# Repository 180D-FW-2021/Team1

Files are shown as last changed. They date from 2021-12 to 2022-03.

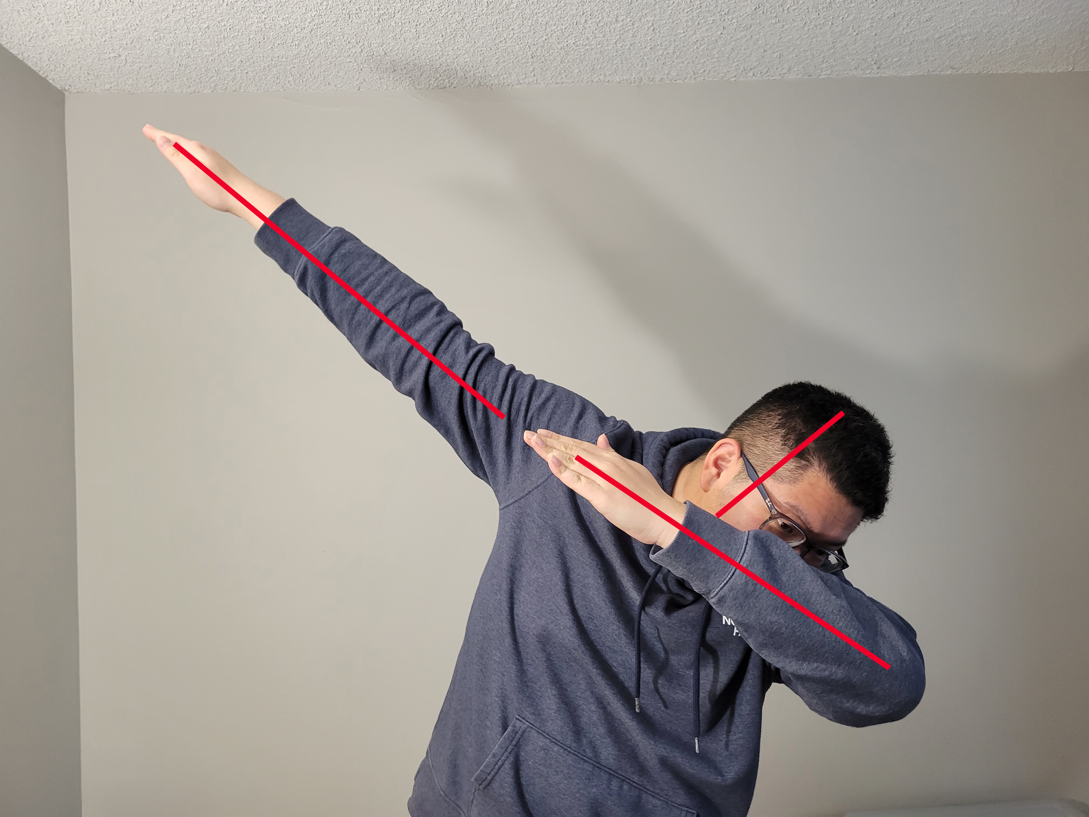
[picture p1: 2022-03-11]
gui/pose_images/Right-Dab.jpg

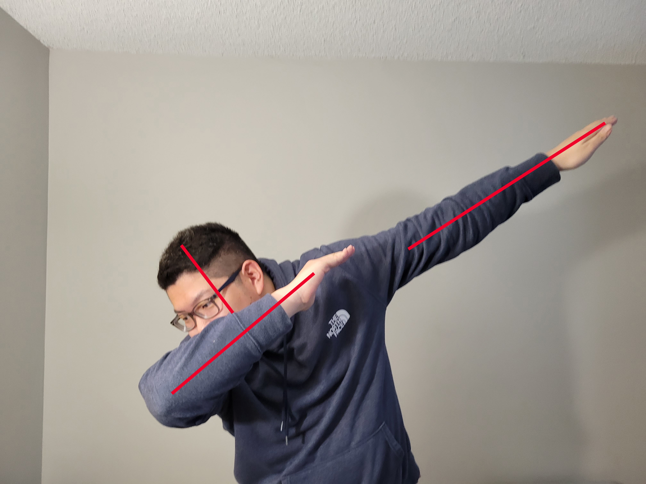
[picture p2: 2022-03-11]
gui/pose_images/Left-Dab.jpg

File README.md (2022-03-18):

# AirController

Being forced to get up and get the remote just to change the volume or channel is a hassle for households that use a TV. To fix this issue, we have decided to prototype AirController, a system that can take in gestures, poses, and speech as inputs and accordingly control a TV based on the user input. The user can make a specific gesture using their hands or body in order to control the TV, or otherwise issue speech commands to control it that way. These alternate control methods aid those who are disabled and unable to use a normal TV remote, as well as those who are not currently within reach of a remote and do not want to go searching for it.

Currently, the AirController can support 5 commands: Power, Channel Up/Down, and Volume Up/Down. These 5 commands are activated in one of three ways: striking a pose in front of the webcam, moving the hand holding a BerryIMU, or speaking a command. 

## Pose Recognition (OpenCV and MediaPipe)
Uses computer vision and image processing to detect specific body positions and poses. Uses MQTT to communicate detected poses to the subscriber Raspberry Pi.

Folder: sample_poses show images of sample poses that are to be detected from the AirController.

Directory: `pose_detection_code`

## Speech Recognition
Uses Google Cloud Speech-to-Text to detect keywords for specific voice commands.  Uses MQTT to communicate detected commands to the subscriber Raspberry Pi.

Directory: `speech`

## Gesture Recognition
Uses a programmed BerryIMU to detect specific hand motions. Uses MQTT to communicate detected gestures to the subscriber Raspberry Pi.

Directory: `gesture`

## GUI
Graphical user interface created with TKinter to help the user orient themselves with the product. Includes video tutorials of how to use the product. Launches the speech recognition and pose recognition modules on the user's computer.

Directory: `gui`

## Communications
Communication interface for the two Raspberry Pis and laptop to talk to one another and the TV. Uses MQTT publisher/subscriber model. Requires paho-mqtt Python library.

Directory: `comms`

## Demonstration
Demonstrations of our individual subcomponents of our projects working.

Directory: `demonstration_videos`

## Download & Set-Up
Please follow the user manual for detailed instructions on how to set up the AirController.

## Controls

Pose (Webcam) - current poses include a right dab (volume up), left dab (volume down), both arms at a 90 degree angle (channel up), both hands together (power), both arms straight and body straight (power), and both arms straight and both legs at a 90 degree angle (channel down). The webcam must properly recognize the user first for it to start working. 

Speech - currently supports keyword detection for "volume", "channel", and "power". To adjust volume, say any combination of "volume" and "up/down". To adjust channel, say any combination of "channel" and "up/down". To turn the TV on or off, say any combination of "power" and "on/off".

Gesture (BerryIMU) - possible gestures include tilt right (volume up), tilt left (volume down), flick right (channel up), flick left (channel down), flick up (power on), and flick down (power off). The BerryIMU should be facing forward and parallel to the ground as its neutral position. For a visual explanation, launch gui.py and view the tutorial videos.

## Credits

Developed by Steven Chu, Maksym Prokopovych, Sierra Rose, and Isaac Xu.

IMUpi.py: this file, and others in the `gesture` directory, are adapted from http://github.com/ozzmaker/BerryIMU.git. 

mainPi.py: this file, and others in the `comms` directory, are adapted from lab 3. Configuring LIRC adapted from https://www.hackster.io/austin-stanton/creating-a-raspberry-pi-universal-remote-with-lirc-2fd581

pose.py: this file, and others in the `pose_detection_code` directory, are adapted from lab 1 as well as various online sources, which are further referenced in the README of the `pose_detection_code` directory. Also adapted from https://bleedai.com/, specifically https://bleedai.com/introduction-to-pose-detection-2/ and https://bleedai.com/introduction-to-pose-detection-and-basic-pose-classification/

speech_processing.py: this file, and others in the `speech` directory, are adapted from example code provided by Google Cloud documentation.
https://cloud.google.com/speech-to-text/docs/samples?hl=en_US

Further credits can be found in the READMEs of each directory.

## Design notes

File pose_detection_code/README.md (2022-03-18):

## Credits

Isaac Xu's responsibility

## Contents

check_dab.py
  - demo code for detecting if a person is in a dab position

check_psy.py
  - demo code for detecting if both arms are at a 90 degree angle
 
check_three_pose.py
  - demo code for detecting three poses: T-pose, tree pose, and Warrior II pose
  
gui_pose_test.py
  - demo code for combining gui and posture detection code
  
hands_together.py
  - demo code for detecting if a person has their hands in close contact
  
jump_stand.py
  - demo code for detecting if a person is either jumping, crouching, or standing
  
left_right.py
  - demo code for detecting if a person is on the right side, left side, or center of the webcam
  
poses.txt
  - current list of poses and how to achieve them
  
together.py
  - posture detection code that detects a right or left dab, arms at 90 degrees, hands placed together, a T-pose, and both arms straight and legs at 90 degrees
  - sends it to poses.py in the main folder so that the command corresponding to the pose is executed
  - requires one available webcam on the computer

Pose Detect.mp4
  - posture detection code in action, showing that dabs change the volume, and a hands-together and T-pose "presses" the power button
  - having both arms at 90 degree angle, or having both arms straight while legs are at a 90 degree angle would change the channel up and down, but that T.V didn't have any channels to change. The signal was still sent to the mqtt.

Pose Detection Trials.mp4
  - all the trials done to detect if there was any errors when detecting poses 

Pose_Demonstration.mp4
  - a demonstration of how to properly use the pose detection to control the AirController

dependencies.txt
  - a list of all the dependencies Isaac's virtual environment uses to run pose detection code

pose_install_script.sh
  - make sure to run this, since it contains the modules that are required to run both pose detection and speech detection code

testing.py
  - testing code that won't interfere with the main approved detection

required installs.txt
  - a list of the required installs (besides those already in Anaconda) needed to run only pose detection code

## Code tags
  Where Isaac got help for the code from
  - https://bleedai.com/introduction-to-pose-detection-2/
  - https://bleedai.com/introduction-to-pose-detection-and-basic-pose-classification/

## Known Bugs

## Improvements
- organize list of dependencies (current list is 300 above dependencies)

## Decisions Made
- this was the default
- current list of poses used because they are easily identifiable and easily done by majority of people, but might have to change in the future
- 6 poses used: two for power, two for channel, two for volume

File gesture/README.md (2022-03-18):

## Credits

All of the code in this directory which gathers sensor information from the BerryIMU is adapted from http://github.com/ozzmaker/BerryIMU.git.

This portion of the project was Sierra's responsibility.

## Information and Statistics

This code gathers a bunch of data from the BerryIMU sensors, sets arbitrary thresholds to detect when certain gestures are executed, and sends MQTT messages to our server with which gesture was detected. There are various flags to detect when a gesture was just made so as to prevent the detection of its opposite gesture within a certain time frame, as many gestures require the Pi to be put back in its original position after. 

Currently, the gesture accuracy is as follows:

Power off: 93%

Power on: 100%

Volume down: 100%

Volume up: 100%

Channel down: 100%

Channel up: 100%

Fall detection: 81%

More statistics can be found in the `gesture_data` directory. The latest data is within `winter_data_final`.

I first made the decision to use the accXangle when detecting volume up/down because it was the value that changed the most while making the gesture and just reading the raw data of the BerryIMU. However, it is somewhat unreliable due in part to its noisiness, and so I will be reviewing my choice of variable next quarter.

I also then made the choice to use faux derivatives in creating difference_gyro_X/difference_gyro_Z to use for detecting "flicking" motions (channel up/down, power on/off). This is because they are much easier than actually deriving anything in Python, and because they serve the same purpose: to see the change over time within a certain reading. By making these faux derivatives of the gyro_X and gyro_Z readings of the BerryIMU, I was able to detect when the user rapidly flicked their IMU in a given direction to be able to detect these gestures.

Similarly, I also created difference_gyro_Y, which is solely used to detect when the Pi is falling. Fall detection has about 81% accuracy in detecting a fall (only tested without the case due to movement constraints with the shorter wire). While detecting falls is important, perhaps more important is not ignoring a user's input, thus causing the fall detection to not be perhaps as sensitive as it could be to get 95%+ accuracy. However, this enables the user to not have their inputs ignored, which is definitively more important than successfully detecting a fall to block excess inputs. Thus, while improvements may be possible, we are satisfied with where the fall detection currently is.

## In the main directory, IMUpi.py is the actual file to run in order to use the files within this directory. None of these files should be executed directly.

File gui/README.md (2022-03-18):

## Credits

This part of the project was everyone's responsibility.

Sierra began the GUI by creating some skeleton code for it, which included the general aesthetic, buttons, and ideas of what to include (such as tutorial videos). 
Steven implemented the tutorial play video buttons, and the controller launch/stop buttons. Isaac implemented more buttons, some layout changes, and the tutorial pictures for his section.

To play a tutorial video, click a button under the "Tutorial Videos" tab. To open a tutorial picture, simply click on the button corresponding to the command you wish to enact. 

To start the controller, press "Start Controller". To stop, press "Stop Controller". There are also options to start only a section of the controller in case that is your preference.

Before running the code, please execute the following commands:
```
pip install python-tk
pip install imageio
pip install playsound
brew install portaudio
```

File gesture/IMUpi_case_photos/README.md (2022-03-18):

This is both the CAD files and a collection of photos showing what the IMU case looks like once printed. There is a hole present for any wires to run through (primarily to recharge the battery onboard). The wire in the photos has been moved out of the way so that you can see the internals. The case was designed and printed by Maksym.

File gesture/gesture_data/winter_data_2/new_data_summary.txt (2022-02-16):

Turn left (volume down):
34/34

Turn right (volume right):
30/31

Flick left (channel down):
31/31

Flick right (channel up):
22/26

Flick up (power on):
25/25

Flick down (power off):
26/27

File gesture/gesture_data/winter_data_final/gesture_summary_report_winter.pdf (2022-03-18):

BerryIMU Gesture Data Breakdown

Filename | Command | Gesture | Variable | Threshold | Accuracy
Turn_right_final_data | Volume up | Tilt right | accYangle | -180 < aYa < -70 | 100%
Turn_left_final_data | Volume down | Tilt left | accYangle | 180 > aYa > 70 | 100%
Flick_right_final_data | Channel up | Flick left | difference_gyro_Z | d_g_Z < -20 | 100%
Flick_left_final_data | Channel down | Flick right | difference_gyro_Z | d_g_Z > 20 | 100%
Flick_up_final_data | Power on | Flick up | difference_gyro_X | d_g_X < -25 | 100%
Flick_down_final_data | Power off | Flick down | difference_gyro_X | d_g_X > 40 | 93%
Fall_detection_data (found within gesture/gesture_data /winter_data_3/ ) | Fall detection | Falling (drop-ping the IMU) | difference_gyro_X, difference_gyro_Y, difference_gyro_Z | (d_g_X > 40 or d_g_X < -40) AND ((d_g_Y < -20 or d_g_Y > 20) OR (d_g_Z < -20 or d_g_Z > 20)) | 81%

BerryIMU gestures with their corresponding commands, as well as the accuracy percentages of each gesture being successfully recognized as its corresponding command, in addition to the variable measured alongside its threshold. Each gesture/command combo underwent 27-38 trials, wherein no output was observed by Sierra such that whether or not a gesture worked correctly was unknown until after the trial ended. AccYangle is a reading taken from the original BerryIMU code Sierra modified from lab 4. Difference_gyro_X, difference_gyro_Y, and difference_gyro_Z are faux derivatives that Sierra created in order to detect change over time between readings of the gyroscope’s sensors, allowing her to detect large changes in its readings in order to accurately recognize a gesture. These readings were all done with the case on the BerryIMU/Raspberry Pi/battery pack, with the exception of the fall_detection_data, where the wire to be used with the case was not long enough to test dropping the BerryIMU.

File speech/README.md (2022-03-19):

## Credits

This part of the project was Steven's responsibility.

Contains `speech_processing.py`, which implements the speech processing module of this project. Transcribes all audio to text, and detects keywords "power", "channel", and "volume".

Code adapted from Google Cloud Speech-to-Text API example code:
https://cloud.google.com/speech-to-text/docs/samples?hl=en_US

In order to run this code, please run the following commands:
```
pip install --upgrade google-cloud-speech
brew install portaudio
pip install pyaudio
```

Also required to run this code is a Google Cloud private key. It has been removed from this public repository, but is available upon request.
After obtaining the key, append `export GOOGLE_APPLICATION_CREDENTIALS="KEY_PATH"` to your ~/.bash_profile file, replacing "KEY_PATH" with the path to the private key on your local machine, and restart your shell.

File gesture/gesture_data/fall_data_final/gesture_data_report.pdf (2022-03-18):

BerryIMU Gesture Data Breakdown

File Directory | Command | Gesture | Variable | Threshold | Accuracy (20 trials)
Right_data | Volume up | Tilt right | accYangle | -180 < aYa < -70 | 60%
Left_data | Volume down | Tilt left | accYangle | 180 > aYa > 70 | 60%
Flick_right_data | Channel up | Flick left | difference_gyro_Z | d_g_Z < -20 | 90%
Flick_left_data | Channel down | Flick right | difference_gyro_Z | d_g_Z > 20 | 85%
Flick_up_data | Power on | Flick up | difference_gyro_X | d_g_X < -40 | 95%
Flick_down_data | Power off | Flick down | difference_gyro_X | d_g_X > 40 | 35%

BerryIMU gestures with their corresponding commands, as well as the accuracy percentages of each gesture being successfully recognized as its corresponding command, in addition to the variable measured alongside its threshold. Each gesture/command combo underwent 20 trials, wherein no output was observed by Sierra such that whether or not a gesture worked correctly was unknown until after the trial ended. AccYangle is a reading taken from the original BerryIMU code Sierra modified from lab 4. Difference_gyro_X and difference_gyro_Z are faux derivatives that Sierra created in order to detect change over time between readings of the gyroscope’s sensors, allowing her to detect large changes in its readings in order to accurately recognize a gesture.

Each directory contains an excel spreadsheet that graphs out each trial of each gesture. Not every graph is correctly labeled, as Sierra only took graphs of interest for such things as the final project report. From there, she put the number of correctly detected gestures somewhere beneath the graphs. All the other files in these directories just contain raw data. The excel spreadsheet compiles them together in a more compact format, but still without labels. For what exactly is being measured, please refer to the above table.

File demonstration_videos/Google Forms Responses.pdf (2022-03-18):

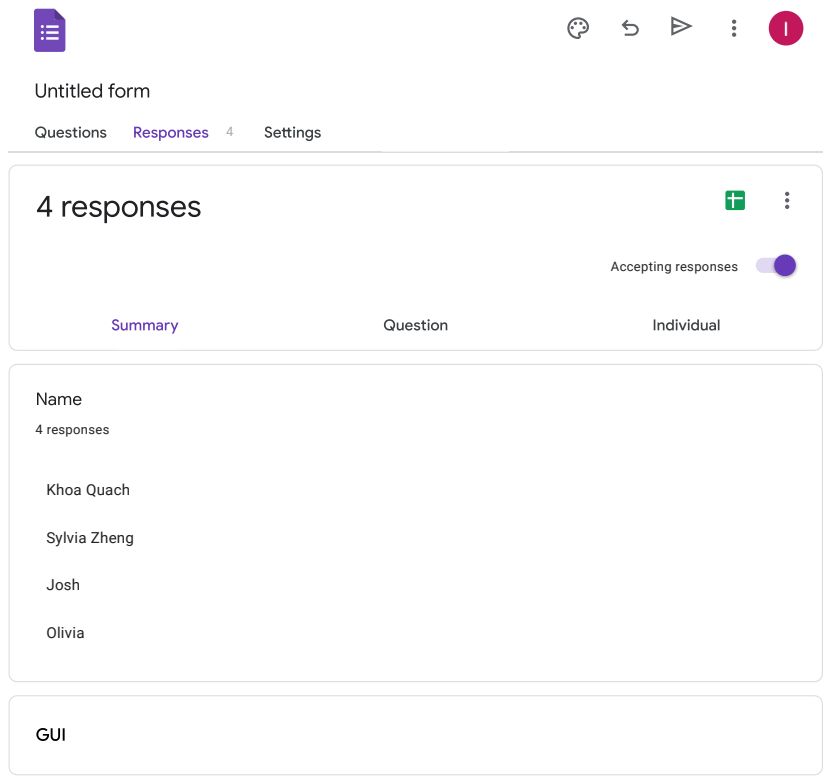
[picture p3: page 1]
4 responses; Accepting responses; Name; Khoa Quach; Sylvia Zheng; Josh; Olivia; GUI; Summary; Question; Individual; Untitled form; Questions; Responses; Settings

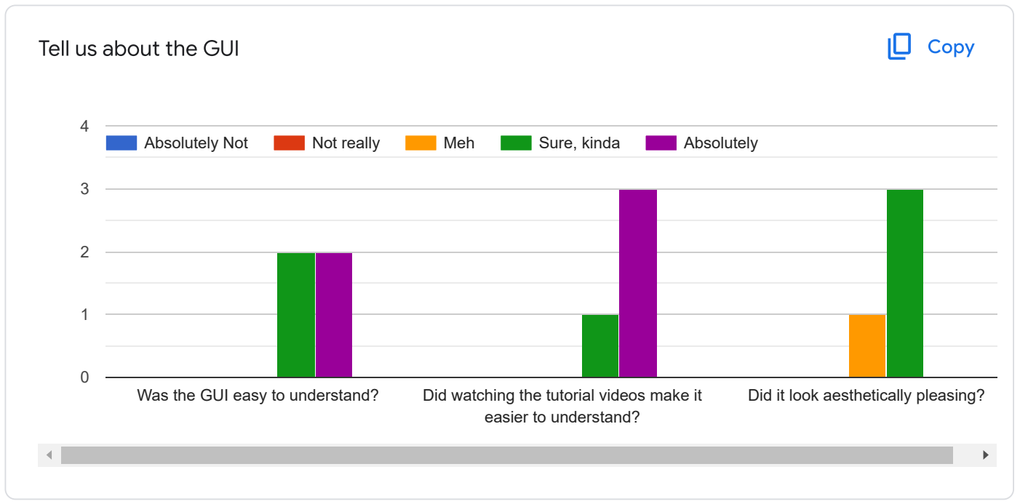
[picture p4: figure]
Tell us about the GUI; Copy; easier to understand?; Did it look aesthetically pleasing?; Absolutely Not; Not really; Meh; Sure, kinda; Absolutely

Are there any improvements/suggestions you have for the GUI?

3 responses

UI is pretty clean and buttons are self-explanatory. I think it might be more user-friendly if you could open the pose videos from the pose recognition page

Nothing really, it does its job

The GUI is great functionally, and I really appreciated all the tutorial videos. I'm not sure if you guys had this, but maybe showing a window of the pose webcam feed within the GUI would make it look more cohesive? Also, if you guys have the time, just minor improvmenets to make the GUI aesthethic :)

Was the GUI easy to understand? Did watching the tutorial videos make it

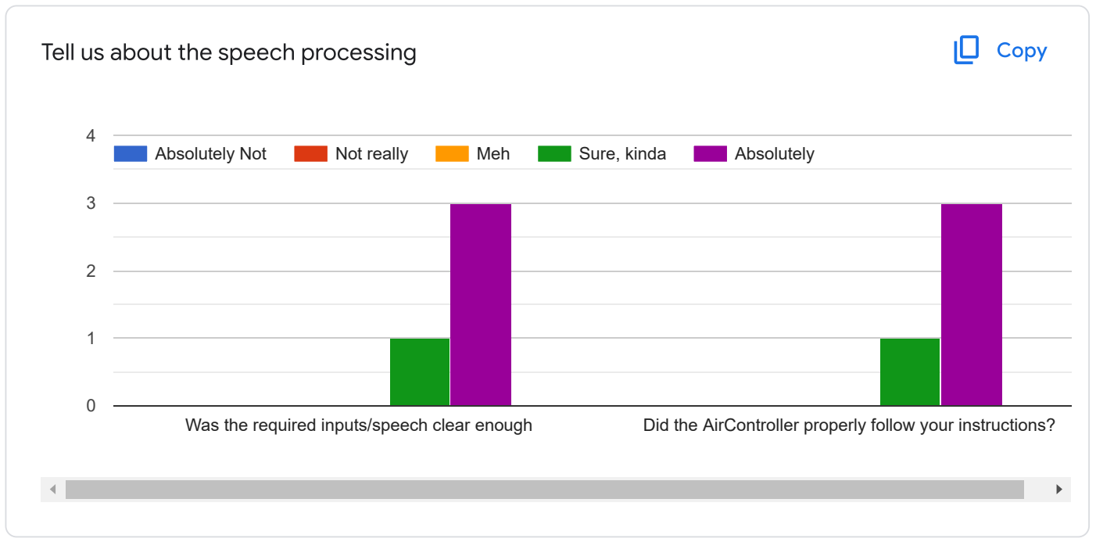
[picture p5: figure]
Tell us about the speech processing; Absolutely Not; Not really; Meh; Sure, kinda; Absolutely
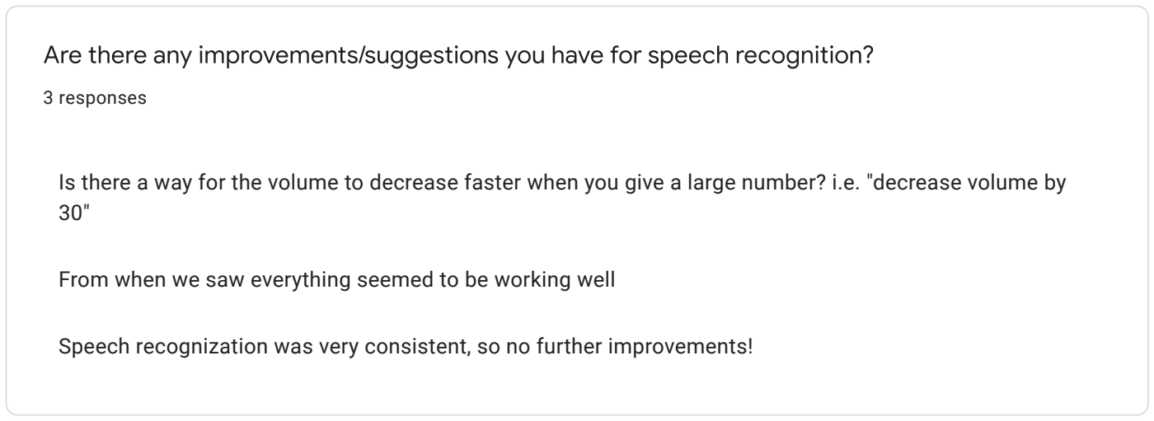
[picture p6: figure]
3 responses

Are there any improvements/suggestions you have for speech recognition?

Is there a way for the volume to decrease faster when you give a large number? i.e. "decrease volume by

From when we saw everything seemed to be working well

Speech recognization was very consistent, so no further improvements!

Was the required inputs/speech clear enough | Did the AirController properly follow your instructions?

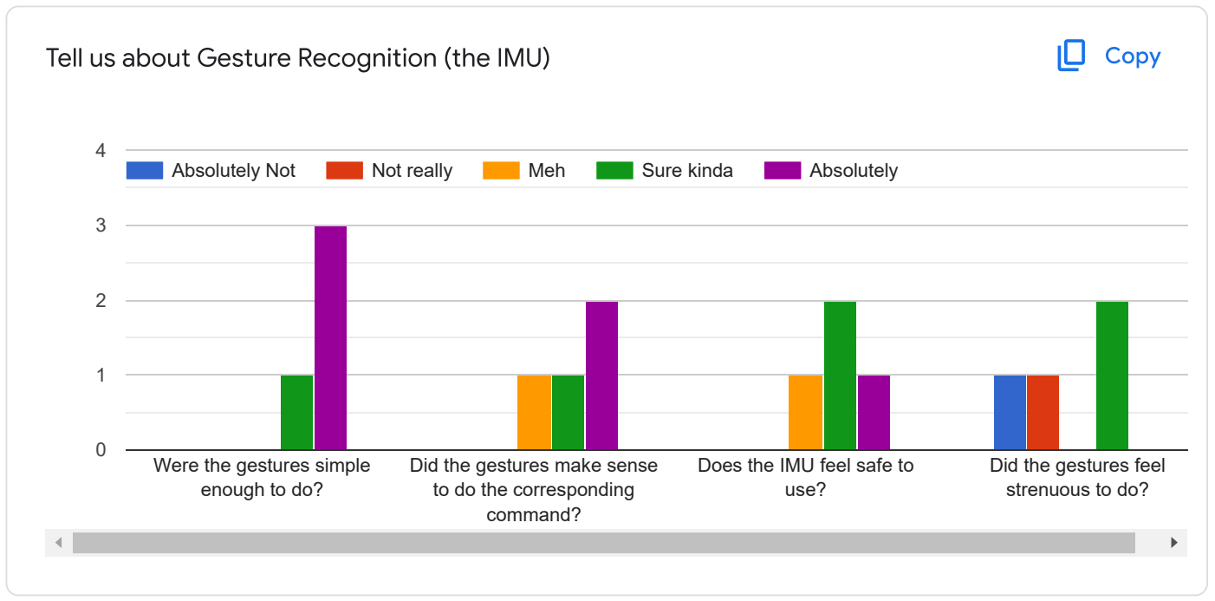
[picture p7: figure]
Were the gestures simple enough to do?; Did the gestures make sense to do the corresponding command?; Does the IMU feel safe to use?; Did the gestures feel strenuous to do?; Absolutely Not; Not really; Meh; Sure kinda; Absolutely

Tell us about Gesture Recognition (the IMU)

Are there any improvements/suggestions you have for gesture recognition?

4 responses

disconnecting issues, but works fine when connected

put the IMU in a box or find some way to keep it together with the Pi. Add some exception handling for if the IMU disconnects

I think just the connection problems were the only issue here

The IMU seemed to disconnect a lot while use, so maybe if soldering it or some other way to keep the wires from detaching can be helpful in making the gesture recognition system more consistent.

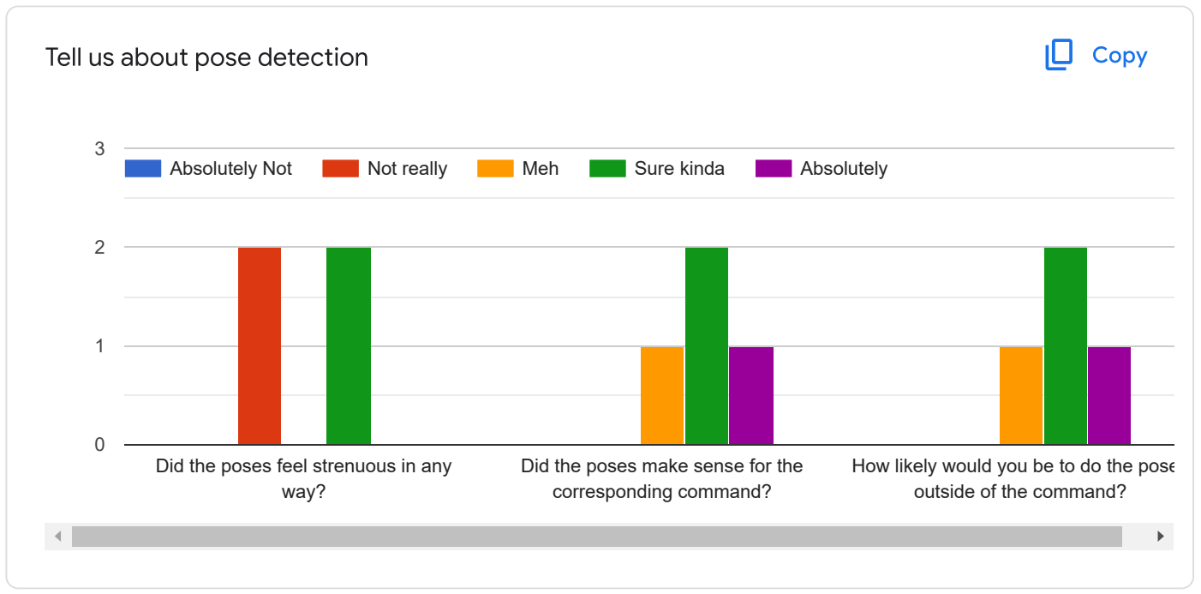
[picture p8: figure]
Tell us about pose detection; Did the poses feel strenuous in any way?; Did the poses make sense for the corresponding command?; How likely would you be to do the pose outside of the command?; Absolutely Not; Not really; Meh; Sure kinda; Absolutely
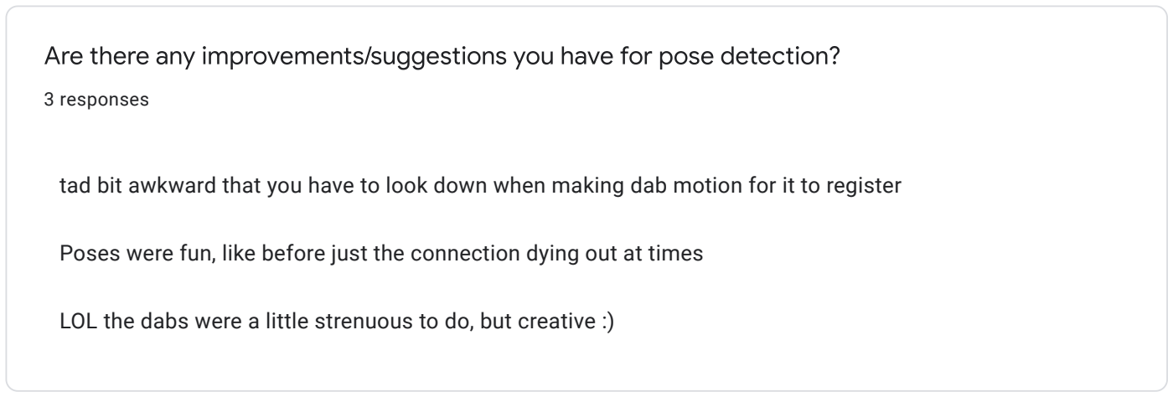
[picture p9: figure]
3 responses

Are there any improvements/suggestions you have for pose detection?

tad bit awkward that you have to look down when making dab motion for it to register

Poses were fun, like before just the connection dying out at times

LOL the dabs were a little strenuous to do, but creative :)

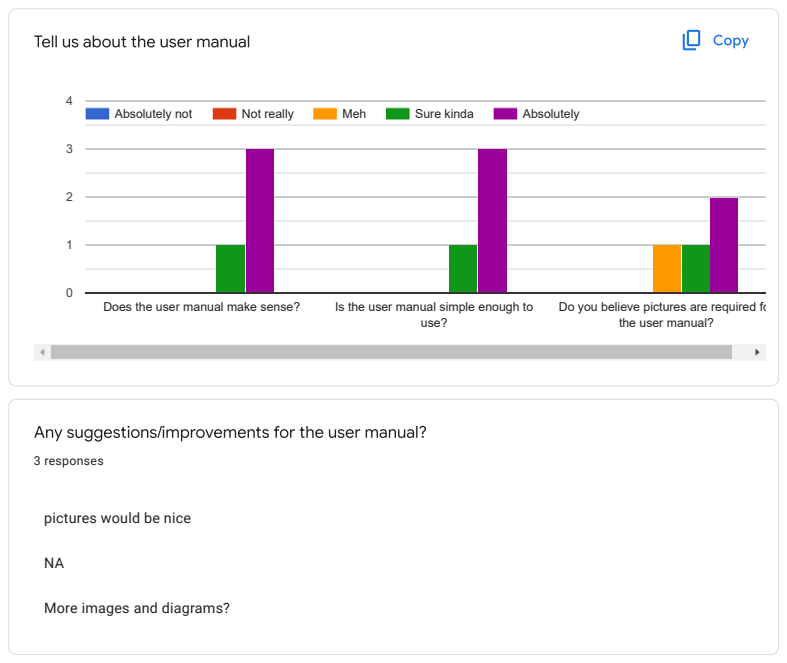
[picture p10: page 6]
3 responses; Does the user manual make sense?; Is the user manual simple enough to; use?; Absolutely not; Not really; Meh; Sure kinda; Absolutely

Tell us about the user manual

Do you believe pictures are required fo

the user manual?

Any suggestions/improvements for the user manual?

pictures would be nice

More images and diagrams?

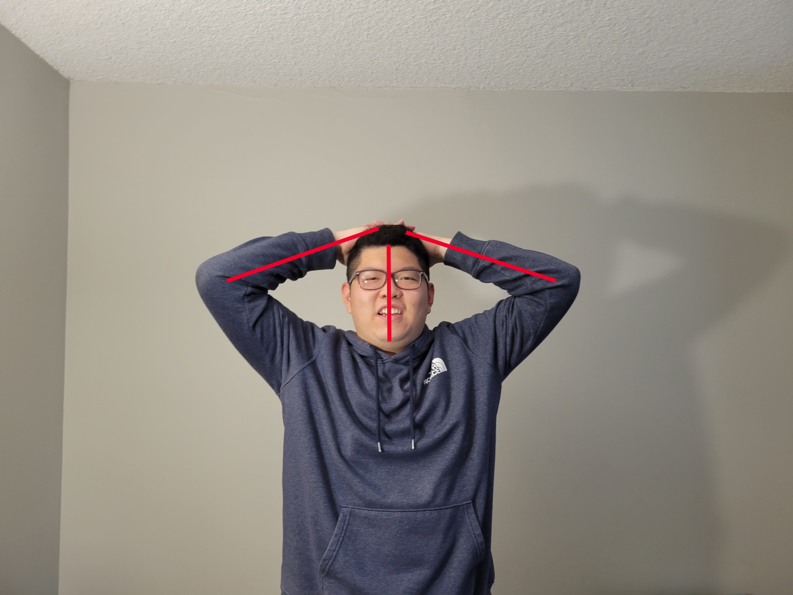
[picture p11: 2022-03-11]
gui/pose_images/Relaxing.jpg

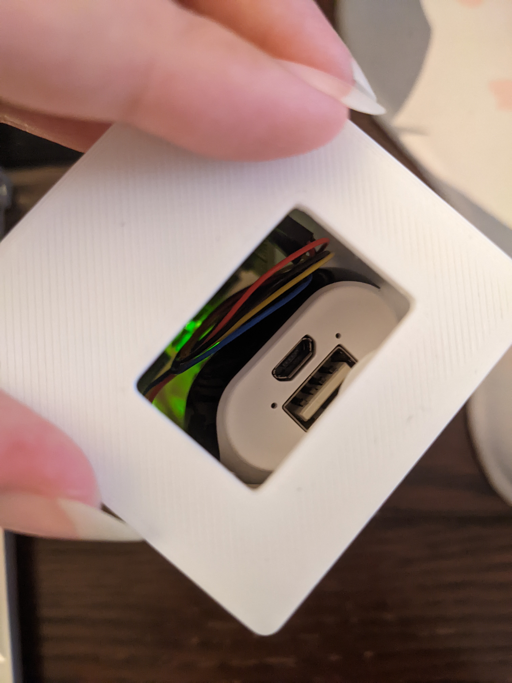
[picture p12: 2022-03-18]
gesture/IMUpi_case_photos/IMUpi_case4.jpg

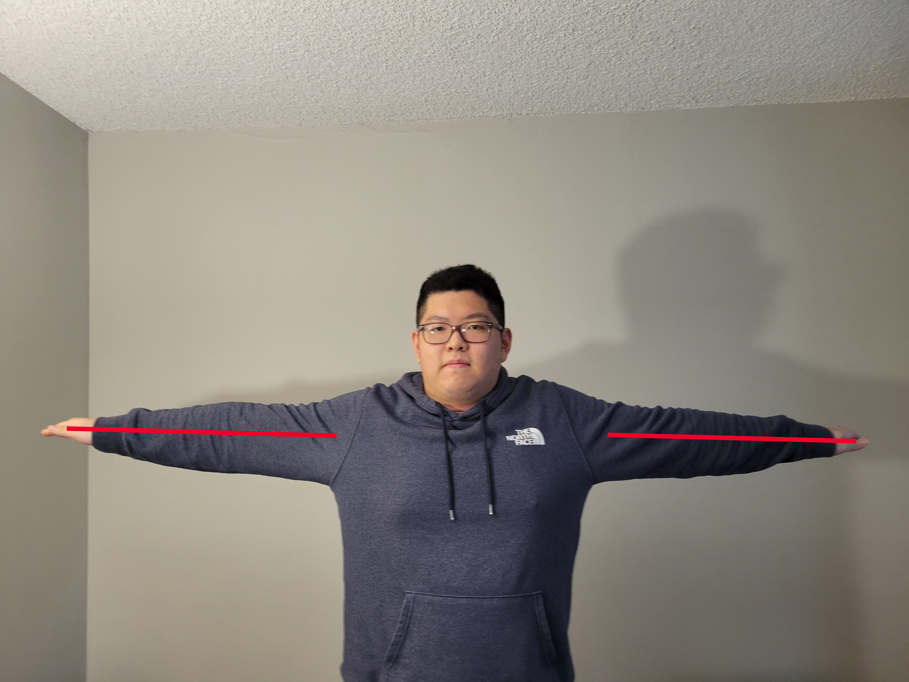
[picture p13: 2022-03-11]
gui/pose_images/T-pose.jpg

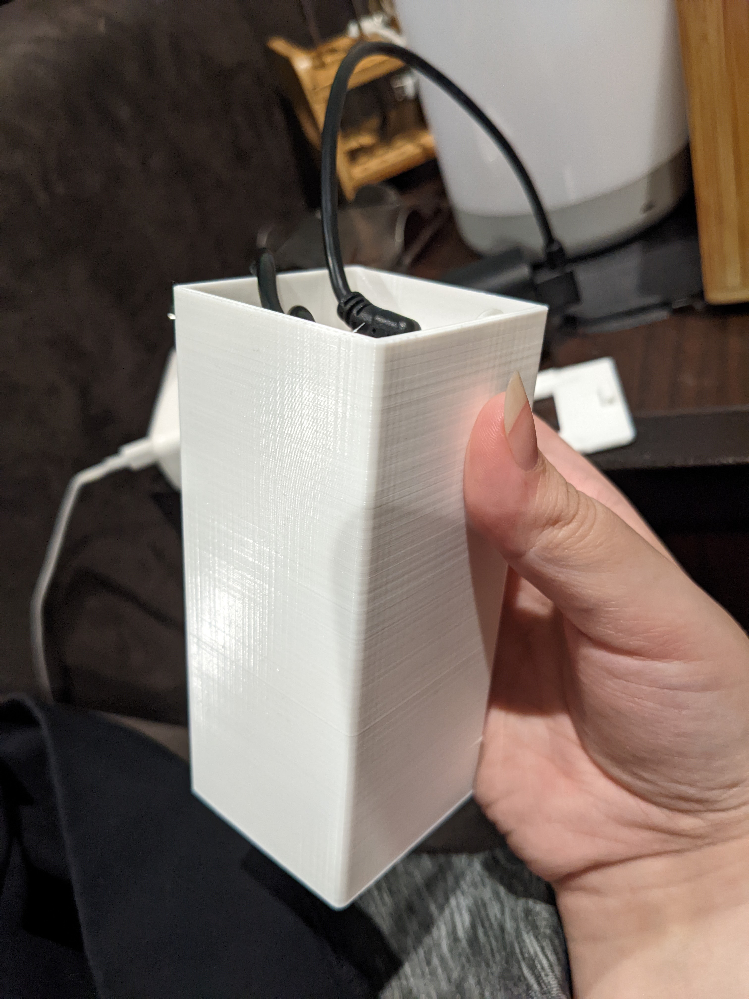
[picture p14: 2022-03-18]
gesture/IMUpi_case_photos/IMUpi_case1.jpg

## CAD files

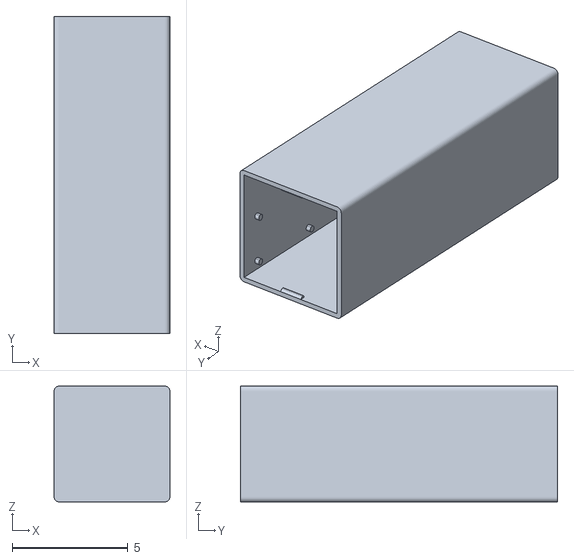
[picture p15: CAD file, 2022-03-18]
gesture/IMUpi_case_photos/180caseMain.stl
5.00 x 13.7 x 5.00

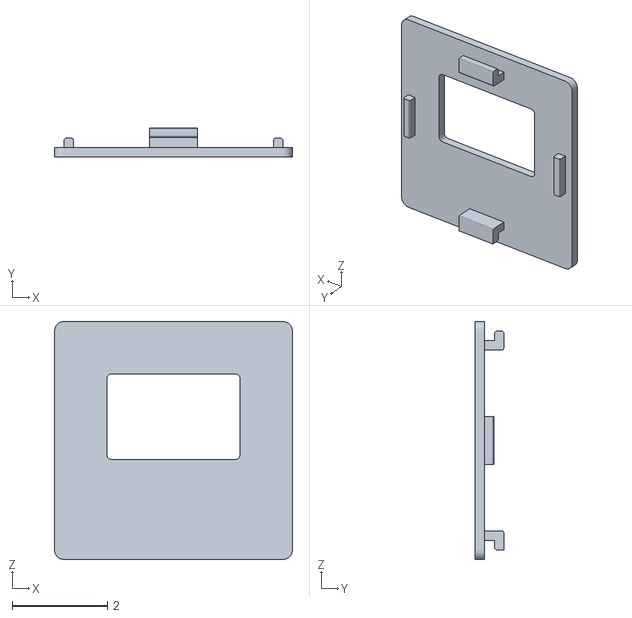
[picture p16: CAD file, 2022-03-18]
gesture/IMUpi_case_photos/180caseTop.stl
5.00 x 0.61 x 5.00

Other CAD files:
gesture/IMUpi_case_photos/180caseMain.ipt
gesture/IMUpi_case_photos/180caseTop.ipt

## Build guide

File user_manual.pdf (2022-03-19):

# AirController User Manual

Steven Chu, Maksym Prokopovych, Sierra Rose, Isaac Xu ECE 180DB, Winter 2022

### Getting Started

Hardware Requirements

The AirController has the following hardware requirements:

1. Two Raspberry Pi Zeros
2. BerryIMU
a. Jumper cables
3. IR emitter and receiver
a. Wires and breadboard to connect these together with one of the Raspberry Pis
4. A computer with a webcam and microphone
5. Wifi signal

Hardware Set-Up

While in an ideal scenario, the user would not be doing any of this set-up as the entire product would come preconfigured, in order to install the AirController onto pre-existing devices, the following set-up must be carried out.

For the first Raspberry Pi, we must set up the BerryIMU with 4 jumper cables, as well as enable I2C communication. For detailed instructions on how to do this, please refer to Lab 4 from fall quarter.

For the second Raspberry Pi, we must set up the IR emitter. The emitter is a standalone 3 pin device, it requires 3 pins, 3.3 V power, ground, and signal pins. The default signal pin is GPIO22, the 8th pin down on the left row of the header, with the “top” being the SD card slot.

If the user so desires, we have also provided CAD files to 3D print a case for the BerryIMU + Raspberry Pi + a suitable battery. While not necessary, the case helps to make the BerryIMU Raspberry Pi more robust, and contributes to a wireless solution for it.

Downloading and Installation

Connect to wifi on both of the Raspberry Pis, as well as the webcam and microphone-enabled computer. From there, download the Team 1 Github repo onto all of the devices. If trouble is experienced with this step, please skip to the disk imaging section below for further instructions on how to connect to wifi.

Computer Set-up

On the webcam and microphone-enabled computer, you must install the necessary software using the installation scripts. If you do not already have Python and pip installed, then please follow these steps:

Download an Anaconda environment (Python)
First run conda install pip -> this will install the pip directory
If it’s already installed, update pip, or skip this step entirely

If the user is struggling to run the given scripts (such as in the case of having a Windows computer), please run each given command in the scripts individually by first installing the necessary software, including Python and pip. This will enable the user to run most commands in the script. The user can skip any commands which do not run aside from these necessary ones using pip, such as apt-get. Please follow the commands listed within total_install_script.sh.

If the user already has Python and pip installed, then please run the total_install_script.sh file to install the AirController.

Raspberry Pi Set-up

On the first Raspberry Pi which is connected to the BerryIMU, run the IMUpi_install_script.sh present within the gesture folder. This will install the necessary dependencies. If desired, follow the instructions within system_config_information.txt in the gesture folder for how to make the program run on boot. Alternatively, you may flash the disk image provided. Further instructions on how to do that can be found below.

On the second Raspberry Pi which is connected to the IR emitter, you can either follow the detailed instructions within the lirc_configs folder’s README, or you can install the disk image provided (preferable). This is because the disk image has everything configured already for IR emission on pin 22 and automatic startup on boot.

Disk Imaging (optional)

Disk imaging can be accomplished with the .iso file by taking your favorite disk image utility (Rufus, dd, etc) and inputting the .iso file, and flashing an SD card with it.

Disk images for the IMU Pi & IR Pi can both be found at: https://drive.google.com/drive/folders/1LgcZ9hz0c_c1fFU0opW7Ngrds5oL3GBd?usp=sharing .

The only change required once imaging on each Pi is changing the wpa_supplicant.conf file (in /etc/wpa_supplicant/wpa_supplicant.conf) to support your local wifi network. Additionally, on the IR Pi, you must select the type of TV used in /home/pi/AirController/config.py. These can be edited either on the SD card itself or by sshing into the Pi (uses the default pi username and password).

### How to Use

The AirController has 3 ways to control a TV. The first is via whole-body poses recognized by the webcam. The second is through gestures using the BerryIMU-enabled Raspberry Pi. The third is via voice commands as heard by the computer. In order to best use each of these components, please continue reading to determine how to control each section.

Webcam-Detected Poses

These are the current postures that would trigger a command. To use, the person must be in camera view such that the upper body is within view, and the person must properly be detected. There must be sufficient lighting so that the camera can see one, and darker color clothing may need to be removed.

Command | Gesture(s) | Requirements
Volume Up | Right Dab | - Head into the right elbow - Distance between head and elbow doesn’t have to be too extreme - Left arm straight and some distance from the right arm
Volume Down | Left Dab | - Head into the left elbow - Distance between head and elbow doesn’t have to be too extreme - Right arm straight and some distance from the left arm
Channel Up | Arms Straight | - Arms make a 180 degree, from left to right - Arms are parallel to the ground - Arms must be in full view
Channel Down | Muscle Man | - Arms are at 90 degree, hands facing upward - Arms must be in full view
Power On/Off | Hands Together Relaxing | Hands Together - Have both hands be touching each other - Wrists must be in full view Relaxing - Have both hands be on top of the head; order doesn’t matter - Wrists must be in full view

BerryIMU Gestures

There are currently 6 possible gestures which you can use to control your TV. Each gesture corresponds to a different command, with detailed tutorial videos being accessible through the GUI for extra assistance. The commands are as follows:

Command | Gesture | Detailed Explanation
Volume up | Tilt right | The BerryIMU should be parallel to the floor while you attempt this gesture. With the BerryIMU and Raspberry Pi combo facing forwards, tilt the entire device to the right.
Volume down | Tilt left | The BerryIMU should be parallel to the floor while you attempt this gesture. With the BerryIMU and Raspberry Pi combo facing forwards, tilt the entire device to the left.
Channel up | Flick right | With the BerryIMU and Raspberry Pi combo facing forwards, quickly flick the device to the right by flicking your wrist outwards.
Channel down | Flick left | With the BerryIMU and Raspberry Pi combo facing forwards, quickly flick the device to the left by flicking your wrist inwards.
Power on | Flick up | With the BerryIMU and Raspberry Pi combo facing forwards, quickly flick the device up.
Power off | Flick down | With the BerryIMU and Raspberry Pi combo facing forwards, quickly flick the device down. It is okay to lift the device first when attempting to flick down.

It is helpful to always have the BerryIMU and Raspberry Pi facing forwards towards the TV, as well as parallel to the floor. When setting down the device, do so without tilting the Pi such that it does not think you are attempting to turn off the TV. The BerryIMU also supports fall detection, so dropping the device (in most cases) will not result in accidental inputs.

Voice Commands

There are currently 6 possible voice commands which you can use to control your TV, along with a few more extensions. Each voice command works by detecting certain keywords in your speech. The exact sentence structure does not matter as long as the keywords are detected. The commands are as follows:

Command | Voice Command
Volume up | “... volume … up.”
Volume up by <x> | “... volume … increase/up … <x>.”
Volume down | “... volume … down.”
Volume down by <x> | “... volume … decrease/down … <x>.”
Channel up | “... channel … up.”
Change channel to <y> | “... channel … <y>.”
Channel down | “... channel … down.”
Power on | “... power … on.”
Power off | “... power … off.”

Please note that it is important for the microphone to pick up your speech clearly. The best accuracy will be achieved by speaking clearly and loudly in a quiet environment. Speaking with the microphone closer will also aid in improving accuracy.

GUI

The GUI of the AirController provides an interface with which to access the webcam and speech portions of the controller. By using the “Start Controller” and “Stop Controller” buttons, the user may enable webcam pose detection and voice command detection to be able to control their TV. There are also other controller options if the user only wishes to launch a certain part of the AirController.

Detailed tutorial videos are also available via the GUI, including those for the 6 BerryIMU gestures and for each of the poses. These provide a baseline for what each gesture is expected to look like, and can help the user determine which gesture to make for each command.

There are also tutorial pictures available via the GUI for the poses to better demonstrate the expected pose by the user in order to properly register the command.

IR Interfacing

Assuming proper setup, the IR emitter should work generally seamlessly. The IR emitting Pi should be placed near the TV, older models tend to prefer a closer setup. Usually the IR receiver on the TV is on the right or sometimes left corner of the TV, the device should be placed within a few feet of it. If it is not picking up the signals, please place it closer and mess around with where to put it.

The IR emitter has a small LED on it indicating when it is transmitting. This can be used to make sure signals are being received through MQTT.

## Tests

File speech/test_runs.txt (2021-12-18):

The following text is the output received from the test runs done for data
collection on the speech module. You can see which trials where there were
misinterpretations.

POWER ON TRIALS:
===============================
COMMAND DETECTED - Powering on
 power on
COMMAND DETECTED - Powering on
 power on 
COMMAND DETECTED - Powering on
 power on 
COMMAND DETECTED - Powering on
 power off
COMMAND DETECTED - Powering off
 power off
COMMAND DETECTED - Powering off
 power on 
COMMAND DETECTED - Powering on
 power on 
COMMAND DETECTED - Powering on
 power off
COMMAND DETECTED - Powering off
 power on 
COMMAND DETECTED - Powering on
 power on 
COMMAND DETECTED - Powering on
 power off
COMMAND DETECTED - Powering off
 power on 
COMMAND DETECTED - Powering on
 power on 
COMMAND DETECTED - Powering on
 power on 
COMMAND DETECTED - Powering on
 power on 
COMMAND DETECTED - Powering on

POWER OFF TRIALS:
===============================
 power off
COMMAND DETECTED - Powering off
 power off
COMMAND DETECTED - Powering off
 power off
COMMAND DETECTED - Powering off
 power off
COMMAND DETECTED - Powering off
 power off
COMMAND DETECTED - Powering off
 power off
COMMAND DETECTED - Powering off
 power off
COMMAND DETECTED - Powering off
 power off
COMMAND DETECTED - Powering off
 power off
COMMAND DETECTED - Powering off
 power off
COMMAND DETECTED - Powering off
 power off
COMMAND DETECTED - Powering off
 power off
COMMAND DETECTED - Powering off
 power off
COMMAND DETECTED - Powering off
 power off
COMMAND DETECTED - Powering off
 power off
COMMAND DETECTED - Powering off
 power off
COMMAND DETECTED - Powering off
 power off
COMMAND DETECTED - Powering off

CHANNEL UP TRIALS:
===============================
 Channel up
COMMAND DETECTED - Channel up
 Channel up
COMMAND DETECTED - Channel up
 Channel up 
COMMAND DETECTED - Channel up
 Channellock
 Channel up
COMMAND DETECTED - Channel up
 Channellock
 Channel up 
COMMAND DETECTED - Channel up
Channellock
 Channel up
COMMAND DETECTED - Channel up
 Channel up
COMMAND DETECTED - Channel up
 Channel up 
COMMAND DETECTED - Channel up
 Channel up
COMMAND DETECTED - Channel up
 Channel up
COMMAND DETECTED - Channel up
 Channel up
COMMAND DETECTED - Channel up
 Channel up
COMMAND DETECTED - Channel up
 Channel up
COMMAND DETECTED - Channel up
 Channel up
COMMAND DETECTED - Channel up
 Channel up
COMMAND DETECTED - Channel up
 Channel up
COMMAND DETECTED - Channel up

CHANNEL DOWN TRIALS:
===============================
 Channel Down
COMMAND DETECTED - Channel Down
 Channel Down
COMMAND DETECTED - Channel Down
 Channel Down
COMMAND DETECTED - Channel Down
 Channel Down
COMMAND DETECTED - Channel Down
 Channel Down
COMMAND DETECTED - Channel Down
 Channel Down
COMMAND DETECTED - Channel Down
 Channel Down
COMMAND DETECTED - Channel Down
 Channel Down
COMMAND DETECTED - Channel Down
 Channel Down
COMMAND DETECTED - Channel Down
 Channel Down
COMMAND DETECTED - Channel Down
 Channel Down
COMMAND DETECTED - Channel Down
 Channel Down
COMMAND DETECTED - Channel Down
 Channel Down
COMMAND DETECTED - Channel Down
 Channel Down
COMMAND DETECTED - Channel Down
 Channel Down
COMMAND DETECTED - Channel Down
 Channel Down
COMMAND DETECTED - Channel Down
 Channel Down
COMMAND DETECTED - Channel Down
 Channel Down
COMMAND DETECTED - Channel Down
 Channel Down
COMMAND DETECTED - Channel Down

VOLUME UP TRIALS:
===============================
 volume up
COMMAND DETECTED - Volume up
 volume up
COMMAND DETECTED - Volume up
 volume up
COMMAND DETECTED - Volume up
 volume up
COMMAND DETECTED - Volume up
 volume up
COMMAND DETECTED - Volume up
 volume up
COMMAND DETECTED - Volume up
 volume up
COMMAND DETECTED - Volume up
 volume up
COMMAND DETECTED - Volume up
 volume up
COMMAND DETECTED - Volume up
 volume up
COMMAND DETECTED - Volume up
 volume up
COMMAND DETECTED - Volume up
 volume up
COMMAND DETECTED - Volume up
 volume up
COMMAND DETECTED - Volume up
 volume up
COMMAND DETECTED - Volume up
 volume up
COMMAND DETECTED - Volume up
 volume up
COMMAND DETECTED - Volume up
 volume up
COMMAND DETECTED - Volume up
 volume up
COMMAND DETECTED - Volume up

VOLUME DOWN TRIALS:
==============================
 volume down
COMMAND DETECTED - Volume down
 volume down
COMMAND DETECTED - Volume down
 volume down
COMMAND DETECTED - Volume down
 volume down
COMMAND DETECTED - Volume down
 volume down
COMMAND DETECTED - Volume down
 volume down
COMMAND DETECTED - Volume down
 volume down
COMMAND DETECTED - Volume down
 volume down
COMMAND DETECTED - Volume down
 volume down
COMMAND DETECTED - Volume down
 volume down
COMMAND DETECTED - Volume down
 volume down
COMMAND DETECTED - Volume down
 volume down
COMMAND DETECTED - Volume down
 volume down
COMMAND DETECTED - Volume down
 volume down
COMMAND DETECTED - Volume down
 volume down
COMMAND DETECTED - Volume down
 volume down
COMMAND DETECTED - Volume down
 volume down
COMMAND DETECTED - Volume down
 volume down
COMMAND DETECTED - Volume down
 volume down
COMMAND DETECTED - Volume down

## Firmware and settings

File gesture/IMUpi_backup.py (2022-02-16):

#!/usr/bin/python
#
#    This program  reads the angles from the acceleromteer, gyroscope
#    and mangnetometer on a BerryIMU connected to a Raspberry Pi.
#
#    This program includes two filters (low pass and median) to improve the
#    values returned from BerryIMU by reducing noise.
#
#    The BerryIMUv1, BerryIMUv2 and BerryIMUv3 are supported
#
#    This script is python 2.7 and 3 compatible
#
#    Feel free to do whatever you like with this code.
#    Distributed as-is; no warranty is given.
#
#    http://ozzmaker.com/



import sys
import time
import math
import gesture.IMU as IMU
import datetime
import os
import comms.comms as comms

server = "broker.hivemq.com"

conn = comms.mqttCommunicator(server, {})

#time.sleep(5)

#conn.send_command("volumeUp")

RAD_TO_DEG = 57.29578
M_PI = 3.14159265358979323846
G_GAIN = 0.070          # [deg/s/LSB]  If you change the dps for gyro, you need to update this value accordingly
AA =  0.40              # Complementary filter constant
MAG_LPF_FACTOR = 0.4    # Low pass filter constant magnetometer
ACC_LPF_FACTOR = 0.4    # Low pass filter constant for accelerometer
ACC_MEDIANTABLESIZE = 9         # Median filter table size for accelerometer. Higher = smoother but a longer delay
MAG_MEDIANTABLESIZE = 9         # Median filter table size for magnetometer. Higher = smoother but a longer delay



################# Compass Calibration values ############
# Use calibrateBerryIMU.py to get calibration values
# Calibrating the compass isnt mandatory, however a calibrated
# compass will result in a more accurate heading value.

magXmin = 774
magYmin = -2363
magZmin = 1115
magXmax = 838
magYmax = -2300
magZmax = 1236

#magXmin =  1326
#magYmin =  -4220
#magZmin =  523
#magXmax =  5032
#magYmax =  -3079
#magZmax =  884

##magXmin  1326  magYmin  -4220  magZmin  523  ## magXmax  5032  magYmax  -3079  magZmax 884

'''
Here is an example:
magXmin =  -1748
magYmin =  -1025
magZmin =  -1876
magXmax =  959
magYmax =  1651
magZmax =  708
Dont use the above values, these are just an example.
'''
############### END Calibration offsets #################

counter_gyro = 0
first_ten_flag = 0

just_flicked_left_flag = 0
just_flicked_right_flag = 0
just_flicked_up_flag = 0
just_flicked_down_flag = 0
just_turned_left_flag = 0
just_turned_right_flag = 0

counter_flicked_left = 0
counter_flicked_right = 0
counter_flicked_up = 0
counter_flicked_down = 0
counter_turned_left = 0
counter_turned_right = 0

FL_detection_counter = 0
FR_detection_counter = 0
FU_detection_counter = 0
FD_detection_counter = 0
TL_detection_counter = 0
TR_detection_counter = 0


mqtt_send_flag = 0
mqtt_counter = 0

#Kalman filter variables
Q_angle = 0.02
Q_gyro = 0.0015
R_angle = 0.005
y_bias = 0.0
x_bias = 0.0
XP_00 = 0.0
XP_01 = 0.0
XP_10 = 0.0
XP_11 = 0.0
YP_00 = 0.0
YP_01 = 0.0
YP_10 = 0.0
YP_11 = 0.0
KFangleX = 0.0
KFangleY = 0.0



def kalmanFilterY ( accAngle, gyroRate, DT):
    y=0.0
    S=0.0

    global KFangleY
    global Q_angle
    global Q_gyro
    global y_bias
    global YP_00
    global YP_01
    global YP_10
    global YP_11

    KFangleY = KFangleY + DT * (gyroRate - y_bias)

    YP_00 = YP_00 + ( - DT * (YP_10 + YP_01) + Q_angle * DT )
    YP_01 = YP_01 + ( - DT * YP_11 )
    YP_10 = YP_10 + ( - DT * YP_11 )
    YP_11 = YP_11 + ( + Q_gyro * DT )

    y = accAngle - KFangleY
    S = YP_00 + R_angle
    K_0 = YP_00 / S
    K_1 = YP_10 / S

    KFangleY = KFangleY + ( K_0 * y )
    y_bias = y_bias + ( K_1 * y )

    YP_00 = YP_00 - ( K_0 * YP_00 )
    YP_01 = YP_01 - ( K_0 * YP_01 )
    YP_10 = YP_10 - ( K_1 * YP_00 )
    YP_11 = YP_11 - ( K_1 * YP_01 )

    return KFangleY

def kalmanFilterX ( accAngle, gyroRate, DT):
    x=0.0
    S=0.0

    global KFangleX
    global Q_angle
    global Q_gyro
    global x_bias
    global XP_00
    global XP_01
    global XP_10
    global XP_11


    KFangleX = KFangleX + DT * (gyroRate - x_bias)

    XP_00 = XP_00 + ( - DT * (XP_10 + XP_01) + Q_angle * DT )
    XP_01 = XP_01 + ( - DT * XP_11 )
    XP_10 = XP_10 + ( - DT * XP_11 )
    XP_11 = XP_11 + ( + Q_gyro * DT )

    x = accAngle - KFangleX
    S = XP_00 + R_angle
    K_0 = XP_00 / S
    K_1 = XP_10 / S

    KFangleX = KFangleX + ( K_0 * x )
    x_bias = x_bias + ( K_1 * x )

    XP_00 = XP_00 - ( K_0 * XP_00 )
    XP_01 = XP_01 - ( K_0 * XP_01 )
    XP_10 = XP_10 - ( K_1 * XP_00 )
    XP_11 = XP_11 - ( K_1 * XP_01 )

    return KFangleX


gyroXangle = 0.0
gyroYangle = 0.0
gyroZangle = 0.0
CFangleX = 0.0
CFangleY = 0.0
CFangleXFiltered = 0.0
CFangleYFiltered = 0.0
kalmanX = 0.0
kalmanY = 0.0
oldXMagRawValue = 0
oldYMagRawValue = 0
oldZMagRawValue = 0
oldXAccRawValue = 0
oldYAccRawValue = 0
oldZAccRawValue = 0

a = datetime.datetime.now()



#Setup the tables for the mdeian filter. Fill them all with '1' so we dont get devide by zero error
acc_medianTable1X = [1] * ACC_MEDIANTABLESIZE
acc_medianTable1Y = [1] * ACC_MEDIANTABLESIZE
acc_medianTable1Z = [1] * ACC_MEDIANTABLESIZE
acc_medianTable2X = [1] * ACC_MEDIANTABLESIZE
acc_medianTable2Y = [1] * ACC_MEDIANTABLESIZE
acc_medianTable2Z = [1] * ACC_MEDIANTABLESIZE
mag_medianTable1X = [1] * MAG_MEDIANTABLESIZE
mag_medianTable1Y = [1] * MAG_MEDIANTABLESIZE
mag_medianTable1Z = [1] * MAG_MEDIANTABLESIZE
mag_medianTable2X = [1] * MAG_MEDIANTABLESIZE
mag_medianTable2Y = [1] * MAG_MEDIANTABLESIZE
mag_medianTable2Z = [1] * MAG_MEDIANTABLESIZE

IMU.detectIMU()     #Detect if BerryIMU is connected.
if(IMU.BerryIMUversion == 99):
    print(" No BerryIMU found... exiting ")
    sys.exit()
IMU.initIMU()       #Initialise the accelerometer, gyroscope and compass


while True:

    #Read the accelerometer,gyroscope and magnetometer values
    ACCx = IMU.readACCx()
    ACCy = IMU.readACCy()
    ACCz = IMU.readACCz()
    GYRx = IMU.readGYRx()
    GYRy = IMU.readGYRy()
    GYRz = IMU.readGYRz()
    MAGx = IMU.readMAGx()
    MAGy = IMU.readMAGy()
    MAGz = IMU.readMAGz()


    #Apply compass calibration
    MAGx -= (magXmin + magXmax) /2
    MAGy -= (magYmin + magYmax) /2
    MAGz -= (magZmin + magZmax) /2


    ##Calculate loop Period(LP). How long between Gyro Reads
    b = datetime.datetime.now() - a
    a = datetime.datetime.now()
    LP = b.microseconds/(1000000*1.0)
#    outputString = "Loop Time %5.2f " % ( LP )



    ###############################################
    #### Apply low pass filter ####
    ###############################################
    MAGx =  MAGx  * MAG_LPF_FACTOR + oldXMagRawValue*(1 - MAG_LPF_FACTOR);
    MAGy =  MAGy  * MAG_LPF_FACTOR + oldYMagRawValue*(1 - MAG_LPF_FACTOR);
    MAGz =  MAGz  * MAG_LPF_FACTOR + oldZMagRawValue*(1 - MAG_LPF_FACTOR);
    ACCx =  ACCx  * ACC_LPF_FACTOR + oldXAccRawValue*(1 - ACC_LPF_FACTOR);
    ACCy =  ACCy  * ACC_LPF_FACTOR + oldYAccRawValue*(1 - ACC_LPF_FACTOR);
    ACCz =  ACCz  * ACC_LPF_FACTOR + oldZAccRawValue*(1 - ACC_LPF_FACTOR);

    oldXMagRawValue = MAGx
    oldYMagRawValue = MAGy
    oldZMagRawValue = MAGz
    oldXAccRawValue = ACCx
    oldYAccRawValue = ACCy
    oldZAccRawValue = ACCz

    #########################################
    #### Median filter for accelerometer ####
    #########################################
    # cycle the table
    for x in range (ACC_MEDIANTABLESIZE-1,0,-1 ):
        acc_medianTable1X[x] = acc_medianTable1X[x-1]
        acc_medianTable1Y[x] = acc_medianTable1Y[x-1]
        acc_medianTable1Z[x] = acc_medianTable1Z[x-1]

    # Insert the lates values
    acc_medianTable1X[0] = ACCx
    acc_medianTable1Y[0] = ACCy
    acc_medianTable1Z[0] = ACCz

    # Copy the tables
    acc_medianTable2X = acc_medianTable1X[:]
    acc_medianTable2Y = acc_medianTable1Y[:]
    acc_medianTable2Z = acc_medianTable1Z[:]

    # Sort table 2
    acc_medianTable2X.sort()
    acc_medianTable2Y.sort()
    acc_medianTable2Z.sort()

    # The middle value is the value we are interested in
    ACCx = acc_medianTable2X[int(ACC_MEDIANTABLESIZE/2)];
    ACCy = acc_medianTable2Y[int(ACC_MEDIANTABLESIZE/2)];
    ACCz = acc_medianTable2Z[int(ACC_MEDIANTABLESIZE/2)];



    #########################################
    #### Median filter for magnetometer ####
    #########################################
    # cycle the table
    for x in range (MAG_MEDIANTABLESIZE-1,0,-1 ):
        mag_medianTable1X[x] = mag_medianTable1X[x-1]
        mag_medianTable1Y[x] = mag_medianTable1Y[x-1]
        mag_medianTable1Z[x] = mag_medianTable1Z[x-1]

    # Insert the latest values
    mag_medianTable1X[0] = MAGx
    mag_medianTable1Y[0] = MAGy
    mag_medianTable1Z[0] = MAGz

    # Copy the tables
    mag_medianTable2X = mag_medianTable1X[:]
    mag_medianTable2Y = mag_medianTable1Y[:]
    mag_medianTable2Z = mag_medianTable1Z[:]

    # Sort table 2
    mag_medianTable2X.sort()
    mag_medianTable2Y.sort()
    mag_medianTable2Z.sort()

    # The middle value is the value we are interested in
    MAGx = mag_medianTable2X[int(MAG_MEDIANTABLESIZE/2)];
    MAGy = mag_medianTable2Y[int(MAG_MEDIANTABLESIZE/2)];
    MAGz = mag_medianTable2Z[int(MAG_MEDIANTABLESIZE/2)];



    #Convert Gyro raw to degrees per second
    rate_gyr_x =  GYRx * G_GAIN
    rate_gyr_y =  GYRy * G_GAIN
    rate_gyr_z =  GYRz * G_GAIN


    #Calculate the angles from the gyro.
    gyroXangle+=rate_gyr_x*LP
    gyroYangle+=rate_gyr_y*LP
    gyroZangle+=rate_gyr_z*LP

    #Convert Accelerometer values to degrees
    AccXangle =  (math.atan2(ACCy,ACCz)*RAD_TO_DEG)
    AccYangle =  (math.atan2(ACCz,ACCx)+M_PI)*RAD_TO_DEG


    #Change the rotation value of the accelerometer to -/+ 180 and
    #move the Y axis '0' point to up.  This makes it easier to read.
    if AccYangle > 90:
        AccYangle -= 270.0
    else:
        AccYangle += 90.0



    #Complementary filter used to combine the accelerometer and gyro values.
    CFangleX=AA*(CFangleX+rate_gyr_x*LP) +(1 - AA) * AccXangle
    CFangleY=AA*(CFangleY+rate_gyr_y*LP) +(1 - AA) * AccYangle

    #Kalman filter used to combine the accelerometer and gyro values.
    kalmanY = kalmanFilterY(AccYangle, rate_gyr_y,LP)
    kalmanX = kalmanFilterX(AccXangle, rate_gyr_x,LP)

    #Calculate heading
    heading = 180 * math.atan2(MAGy,MAGx)/M_PI

    #Only have our heading between 0 and 360
    if heading < 0:
        heading += 360

    ####################################################################
    ###################Tilt compensated heading#########################
    ####################################################################
    #Normalize accelerometer raw values.
    accXnorm = ACCx/math.sqrt(ACCx * ACCx + ACCy * ACCy + ACCz * ACCz)
    accYnorm = ACCy/math.sqrt(ACCx * ACCx + ACCy * ACCy + ACCz * ACCz)


    #Calculate pitch and roll
    pitch = math.asin(accXnorm)
    roll = -math.asin(accYnorm/math.cos(pitch))


    #Calculate the new tilt compensated values
    #The compass and accelerometer are orientated differently on the the BerryIMUv1, v2 and v3.
    #This needs to be taken into consideration when performing the calculations

    #X compensation
    if(IMU.BerryIMUversion == 1 or IMU.BerryIMUversion == 3):            #LSM9DS0 and (LSM6DSL & LIS2MDL)
        magXcomp = MAGx*math.cos(pitch)+MAGz*math.sin(pitch)
    else:                                                                #LSM9DS1
        magXcomp = MAGx*math.cos(pitch)-MAGz*math.sin(pitch)

    #Y compensation
    if(IMU.BerryIMUversion == 1 or IMU.BerryIMUversion == 3):            #LSM9DS0 and (LSM6DSL & LIS2MDL)
        magYcomp = MAGx*math.sin(roll)*math.sin(pitch)+MAGy*math.cos(roll)-MAGz*math.sin(roll)*math.cos(pitch)
    else:                                                                #LSM9DS1
        magYcomp = MAGx*math.sin(roll)*math.sin(pitch)+MAGy*math.cos(roll)+MAGz*math.sin(roll)*math.cos(pitch)





    #Calculate tilt compensated heading
    tiltCompensatedHeading = 180 * math.atan2(magYcomp,magXcomp)/M_PI

    if tiltCompensatedHeading < 0:
        tiltCompensatedHeading += 360


    ##################### END Tilt Compensation ########################
    outputString = ""

    #just_flicked_right_flag = 0
    #just_flicked_left_flag = 0
#    outputString += AccXangle

###########################LEFT/RIGHT TURNS#############################

    #detect left/right turns
    if (AccYangle > 70 and just_turned_right_flag == 0 and just_flicked_up_flag == 0 and just_flicked_down_flag == 0 and just_flicked_left_flag == 0 and just_flicked_right_flag == 0 ):
        TL_detection_counter = TL_detection_counter + 1
        outputString += "LEFT TURN DETECTED!\t"
        just_turned_left_flag = 1
        if (TL_detection_counter >= 3):
            mqtt_send_flag = 1
    if(AccYangle < -70 and just_turned_left_flag == 0 and just_flicked_up_flag == 0 and just_flicked_down_flag == 0 and just_flicked_left_flag == 0 and just_flicked_right_flag == 0):
        TR_detection_counter = TR_detection_counter + 1
        outputString += "RIGHT TURN DETECTED!\t"
        just_turned_right_flag = 1
        if (TR_detection_counter >= 3):
            mqtt_send_flag = 1

    if(just_turned_left_flag):
        counter_turned_left = counter_turned_left + 1
    if(just_turned_right_flag):
        counter_turned_right = counter_turned_right + 1

    if(counter_turned_left >= 10):
        counter_turned_left = 0
        TL_detection_counter = 0
        just_turned_left_flag = 0
    if(counter_turned_right >= 10):
        counter_turned_right = 0
        TR_detection_counter = 0
        just_turned_right_flag = 0

##########################FLICKING LEFT/RIGHT##########################

    #flags/counters for flicking left/right
    if(just_flicked_right_flag): #make counters to see how long it's been since we first detected a flick
        counter_flicked_right = counter_flicked_right + 1
    if(just_flicked_left_flag):
        counter_flicked_left = counter_flicked_left + 1
        #print(counter_flicked_left)

    if(counter_flicked_right == 15):
        just_flicked_right_flag = 0 #reset flag so that we can flick left again
        counter_flicked_right = 0
        FR_detection_counter = 0
    if(counter_flicked_left == 15):
        just_flicked_left_flag = 0 #reset flag so that we can flick right again
        counter_flicked_left = 0
        FL_detection_counter = 0

#########################FLICKING UP/DOWN############################

    if(just_flicked_up_flag): #make counters to see how long it's been since we first detected a flick
        counter_flicked_up = counter_flicked_up + 1
    if(just_flicked_down_flag):
        counter_flicked_down = counter_flicked_down + 1

    if(counter_flicked_up == 50): #high counter here since nobody is trying to turn a tv on then immediately off again, and vice versa
        just_flicked_up_flag = 0 #reset so that we can flick down again
        counter_flicked_up = 0
        FU_detection_counter = 0
    if(counter_flicked_down == 50):
        just_flicked_down_flag = 0 #reset so that we can flick up again
        counter_flicked_down = 0
        FD_detection_counter = 0

#########################GYROSCOPE READINGS#########################

    #flags/counters for flicking left/right (gyroscope readings)
    if(first_ten_flag == 0):
        counter_array_gyro_z = [0, 0, 0, 0, 0, 0, 0, 0, 0, 0]
        counter_array_gyro_x = [0, 0, 0, 0, 0, 0, 0, 0, 0, 0]

    counter_array_gyro_x[counter_gyro] = gyroXangle
    counter_array_gyro_z[counter_gyro] = gyroZangle
    counter_gyro = counter_gyro + 1
    #print(counter_array_fp)
    #print(counter)

    if(counter_gyro == 10):
        counter_gyro = 0
        first_ten_flag = 1


    difference_gyro_Z = 0
    difference_gyro_X = 0
    if(first_ten_flag == 1):
        #print(counter_array_fp)
        #print(gyroZangle)
        difference_gyro_Z = gyroZangle - counter_array_gyro_z[counter_gyro]
        difference_gyro_X = gyroXangle - counter_array_gyro_x[counter_gyro]
        #counter_array_fp[counter] = gyroZangle
        #print(difference_gyro_Z)
    #    if(difference_gyro_Z > 5):
     #       outputString += "FORWARD PUSH DETECTED!"

#    if(CFangleX < -45):
#        outputString += "\tUPWARD LIFT DETECTED!"


#############################FLICKING OUTPUTS###########################

    #reset flags/counters, output detection
    if(difference_gyro_Z > 20 and just_flicked_right_flag == 0 and just_turned_right_flag == 0 and just_flicked_up_flag == 0 and just_flicked_down_flag == 0 and just_turned_left_flag == 0):
        just_flicked_left_flag = 1
        counter_flicked_left = 1
        FL_detection_counter = FL_detection_counter + 1 #if there's at least 5 of this input
        outputString += "\tLEFT FLICK DETECTED!"
        if (FL_detection_counter >= 5):
            mqtt_send_flag = 1
    if(difference_gyro_Z < -20 and just_flicked_left_flag == 0 and just_turned_left_flag == 0 and just_flicked_up_flag == 0 and just_flicked_down_flag == 0 and just_turned_left_flag == 0):
        just_flicked_right_flag = 1
        counter_flicked_right = 1
        FR_detection_counter = FR_detection_counter + 1
        outputString += "\tRIGHT FLICK DETECTED!"
        if (FR_detection_counter >= 5):
            mqtt_send_flag = 1

    if(difference_gyro_X > 40 and just_flicked_left_flag == 0 and just_flicked_right_flag == 0 and FU_detection_counter < 8): #bigger numbers so that it's not as sensitive
        #it's possible that it detected a flick up right before this, so fix that
        just_flicked_up_flag = 0
        counter_flicked_up = 0
        just_flicked_down_flag = 1
        counter_flicked_down = 1
        FU_detection_counter = 0
        FD_detection_counter = FD_detection_counter + 1
        outputString += "\tFLICK DOWN DETECTED"
        if (FD_detection_counter >= 8):
            mqtt_send_flag = 1
    if(difference_gyro_X < -40 and just_flicked_down_flag == 0 and just_flicked_left_flag == 0 and just_flicked_right_flag == 0 and FU_detection_counter < 8):
        just_flicked_up_flag = 1
        counter_flicked_up = 1
        FU_detection_counter = FU_detection_counter + 1
        outputString += "\tFLICK UP DETECTED"
        if (FU_detection_counter >= 8):
            mqtt_send_flag = 1


###########################MQTT HANDLING##############################

    if (mqtt_send_flag == 1):
        outputString += "\tMQTT SEND FLAG ON!"
        if (mqtt_counter == 0): #first time
            #send mqtt thing
            if 1:
                outputString += "\tSEND MQTT"
            if 0:
                outputString += "\nTL_detection_counter: %5.2f" % TL_detection_counter
                outputString += "\nTR_detection_counter: %5.2f" % TR_detection_counter
                outputString += "\nFL_detection_counter: %5.2f" % FL_detection_counter
                outputString += "\nFR_detection_counter: %5.2f" % FR_detection_counter
                outputString += "\nFD_detection_counter: %5.2f" % FD_detection_counter
                outputString += "\nFU_detection_counter: %5.2f" % FU_detection_counter
                outputString += "\n"
            if(TL_detection_counter >= 3):
                outputString += "\tSEND \"TURN LEFT\" MQTT SIGNAL"
                conn.send_command("volumeDown")
                #TL_detection_counter = 0
                #TR_detection_counter = 0 
            if(TR_detection_counter >= 3):
                outputString += "\tSEND \"TURN RIGHT\" MQTT SIGNAL"
                conn.send_command("volumeUp")
                #TR_detection_counter = 0
                #TL_detection_counter = 0
            if(FL_detection_counter >= 5):
                outputString += "\tSEND \"FLICK LEFT\" MQTT SIGNAL"
                conn.send_command("channelDown")
            if(FR_detection_counter >= 5):
                outputString += "\tSEND \"FLICK RIGHT\" MQTT SIGNAL"
                conn.send_command("channelUp")
            if(FD_detection_counter >= 5):
                conn.send_command("power")
                outputString += "\tSEND \"FLICK DOWN\" MQTT SIGNAL"
            if(FU_detection_counter >= 5):
                conn.send_command("power")
                outputString += "\tSEND \"FLICK UP\" MQTT SIGNAL"
            #mqtt_counter = 0 #placeholder line

        mqtt_counter = mqtt_counter + 1
        if (mqtt_counter >= 15): #wait at least 15 cycles to reset ability to send mqtt messages
            mqtt_counter = 0
            mqtt_send_flag = 0


###########################DEBUGGING INFORMATION######################

    if 0:                       #Change to '0' to stop showing the angles from the accelerometer
        outputString += "\t# ACCX Angle %5.2f ACCY Angle %5.2f  #  " % (AccXangle, AccYangle)

    if 0:
        outputString += "%5.2f" % (AccXangle)

    if 0:                       #Change to '0' to stop  showing the angles from the gyro
        outputString +="\t# GRYX Angle %5.2f  GYRY Angle %5.2f  GYRZ Angle %5.2f # " % (gyroXangle,gyroYangle,gyroZangle)

    if 0:                       #Change to '0' to stop  showing the angles from the complementary filter
        outputString +="\t#  CFangleX Angle %5.2f   CFangleY Angle %5.2f  #" % (CFangleX,CFangleY)

    if 0:                       #Change to '0' to stop  showing the heading
        outputString +="\t# HEADING %5.2f  tiltCompensatedHeading %5.2f #" % (heading,tiltCompensatedHeading)

    if 0:                       #Change to '0' to stop  showing the angles from the Kalman filter
        outputString +="# kalmanX %5.2f   kalmanY %5.2f #" % (kalmanX,kalmanY)

    print(outputString)

    #slow program down a bit, makes the output more readable
    time.sleep(0.03)

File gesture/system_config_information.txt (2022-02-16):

On your Raspberry Pi, run the following commands in order to get IMUpi.py to run on boot:

$ cd /etc/systemd/system 
$ sudo touch 180D.service 
$ sudo nano 180D.service

Within 180D.service, copy/paste the following (while modifying the necessary directories):

###

[Unit]
Description=Service for UCLA's ECE 180D class
After=network.target

[Service]
Type=simple
Restart=always
RestartSec=1
User=pi #modify user as needed
ExecStart=python3 /home/pi/Desktop/180da/Team1/IMUpi.py #modify directory as needed
WorkingDirectory=/home/pi/Desktop/180da/Team1/ #modify directory as needed

[Install]
WantedBy=multi-user.target

###

Save and exit.
Then run the following commands:

$ systemctl enable 180D.service
$ systemctl start 180D.service

Your Raspi will now boot IMUpi.py on boot.

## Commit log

2021-11-18 update jump_stand to an actual camera kek
2021-11-25 Update gui_pose_test.py
    added a dab button, which starts up the check_dab code
    when a dab is detected, show a window that says a dab has been detected
2021-11-25 IMU files somewhat working
2021-12-06 controller buttons now launch both speech and cv; added stop controller button
2021-12-06 switching commands
2021-12-06 video file
    Added a video file that showed current pose detecctino working
    Currently this detected 6 different poses, including some errors
2022-01-06 Update pose.py
    Created a counter that keeps track of the time that a commands happens
2022-01-20 basic installation script of dependencies on the IMUpi
2022-01-20 added 'run on boot' instructions
    [system_config_information.txt]
2022-01-20 new data after changes to IMUpi.py to add robustness
2022-01-27 update
    updated the timer function so that the code won't stop if doing something
2022-02-02 Added configs for most major TV brands, fixed LIRC hanging and transitioned to Python library, created global config file, switched MQTT server, removed unneeded files, added systemd service config
2022-02-21 added buttond
    added additional buttons to separate detections
2022-02-24 images
    added images and corresponding buttons for gui's pose checks
2022-03-11 Update gui.py
    update 3 more buttons that close their respective detections
2022-03-12 MQTT fixes, disabled qos for causing problems, also disabled subscribing for send only devices
2022-03-12 Fixed IR emitting device not subscribing
2022-03-18 data with case
2022-03-18 winter final data (with case)
2022-03-18 increasing sensitivity of power on gesture; case makes gesture more difficult
2022-03-18 photos of the case for the IMUpi
2022-03-18 IMUpi case photos
2022-03-18 replacing tutorial videos with IMU + case version
2022-03-18 Added IMU Pi Case Design Files
    [180caseMain.ipt, 180caseMain.stl, 180caseTop.ipt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]
